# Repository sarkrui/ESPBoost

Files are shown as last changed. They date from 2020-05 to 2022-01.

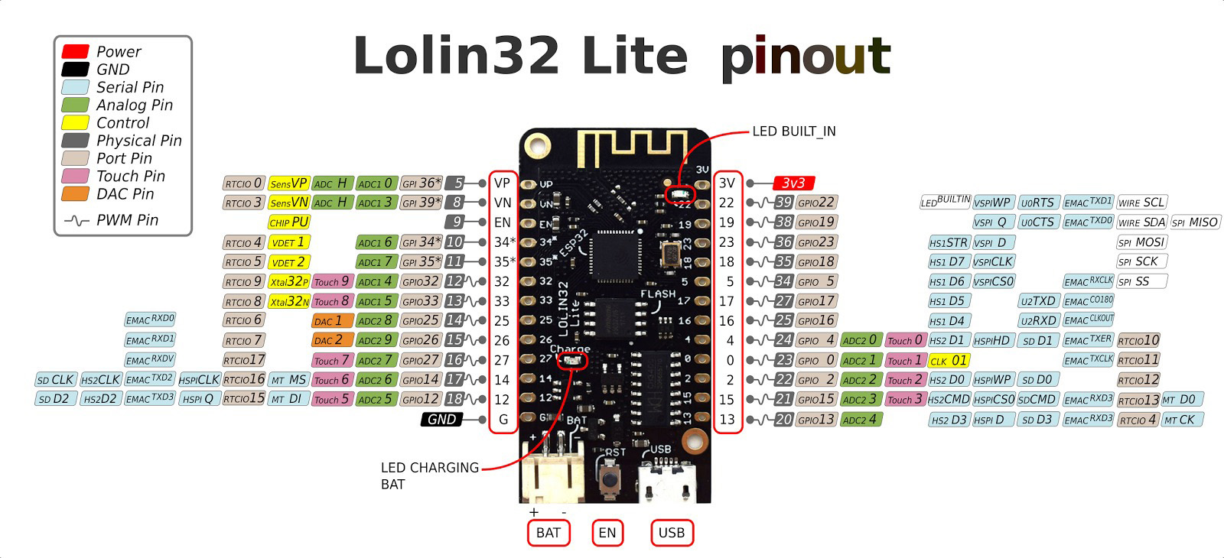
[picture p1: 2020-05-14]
Lolin32_files/Lolin32 Pinout.jpeg

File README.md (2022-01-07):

# ESPBoost
2SDCT8eYnrJI9NF

### Introduction
The ESPBoost is an ESP32 shield combines a **MPU6050** (3-axis gyro/accelerometer, via **SDA/SCL** GPIO), 2 H-Bridge motor drivers (**L9110s**, via GPIO **5**, **16**,**17**,**18** ), and a DC-DC (4.5V ~17v to 5V) power regulator (for powering up the ESP board via USB, allowing to charge Li-Po and the ESP32 MCU). Attaching this shield onto a Lolin32, actuations that demand high current (max. 800mA for each bridge), for example, driving two DC motors, and detections of angles, acceleration can be easily made possible. 

7GoLlhcizVjvBqO

### Components

* **Dual L9110s** (800 mA) DACs
* **MPU6050** Accelerometer and Gyroscope
* **TPS563201** Voltage regulator (4.5v to 17v input, 3A output)
* **FSR** (force sensitive resistor) connector  (A2 section)

### To-do

- [ ]  Include support for ESP32 minikit 
- [ ]  Incoporate [daisy chain support](https://i.imgur.com/pLPUlMk.jpg) for ESP boards (e.g. [TTGO T-Base](https://www.aliexpress.com/item/32888680096.html)) that come with an i2c connector (consisting of`SDA/SCL/3.3/GND` )
- [ ]  Add **ESPBoost-Input**, configured with 3-axis gyro/accelerometer (MPU6050), 12-pin capacitive sensor (MPR121q), FSR pull-down resistors
- [ ]  Add **ESPBoost-Actuation**, consisting of 2 sets of `TB6612FNG`
- [ ]  Add **ESPBoost-Power**, supporting battery charging, regulating voltage from 3.7V to 5V, 9V, 12V

### Pinout 

9usdo4JG2DMlhZ7

### Sample 
If you're interested in the field of Internet of Tangible Things, this shield may help. For sample inquiry, please drop me an email hi@pxing.design

### BibTex

```
@inproceedings{DBLP:conf/ewsn/XingC21,
  author    = {Sark Xing and
               Yaliang Chuang},
  title     = {ESPBoost: {A} Rapid Prototyping Toolkit for Helping Designers Create
               the Internet of Tangible Things},
  booktitle = {CHIIoT@EWSN/EICS},
  series    = {{CEUR} Workshop Proceedings},
  volume    = {2996},
  publisher = {CEUR-WS.org},
  year      = {2021}
}
```

### License

MIT License

Copyright (c) 2020 Sark Xing

Permission is hereby granted, free of charge, to any person obtaining a copy
of this software and associated documentation files (the "Software"), to deal
in the Software without restriction, including without limitation the rights
to use, copy, modify, merge, publish, distribute, sublicense, and/or sell
copies of the Software, and to permit persons to whom the Software is
furnished to do so, subject to the following conditions:

The above copyright notice and this permission notice shall be included in all
copies or substantial portions of the Software.

THE SOFTWARE IS PROVIDED "AS IS", WITHOUT WARRANTY OF ANY KIND, EXPRESS OR
IMPLIED, INCLUDING BUT NOT LIMITED TO THE WARRANTIES OF MERCHANTABILITY,
FITNESS FOR A PARTICULAR PURPOSE AND NONINFRINGEMENT. IN NO EVENT SHALL THE
AUTHORS OR COPYRIGHT HOLDERS BE LIABLE FOR ANY CLAIM, DAMAGES OR OTHER
LIABILITY, WHETHER IN AN ACTION OF CONTRACT, TORT OR OTHERWISE, ARISING FROM,
OUT OF OR IN CONNECTION WITH THE SOFTWARE OR THE USE OR OTHER DEALINGS IN THE
SOFTWARE.

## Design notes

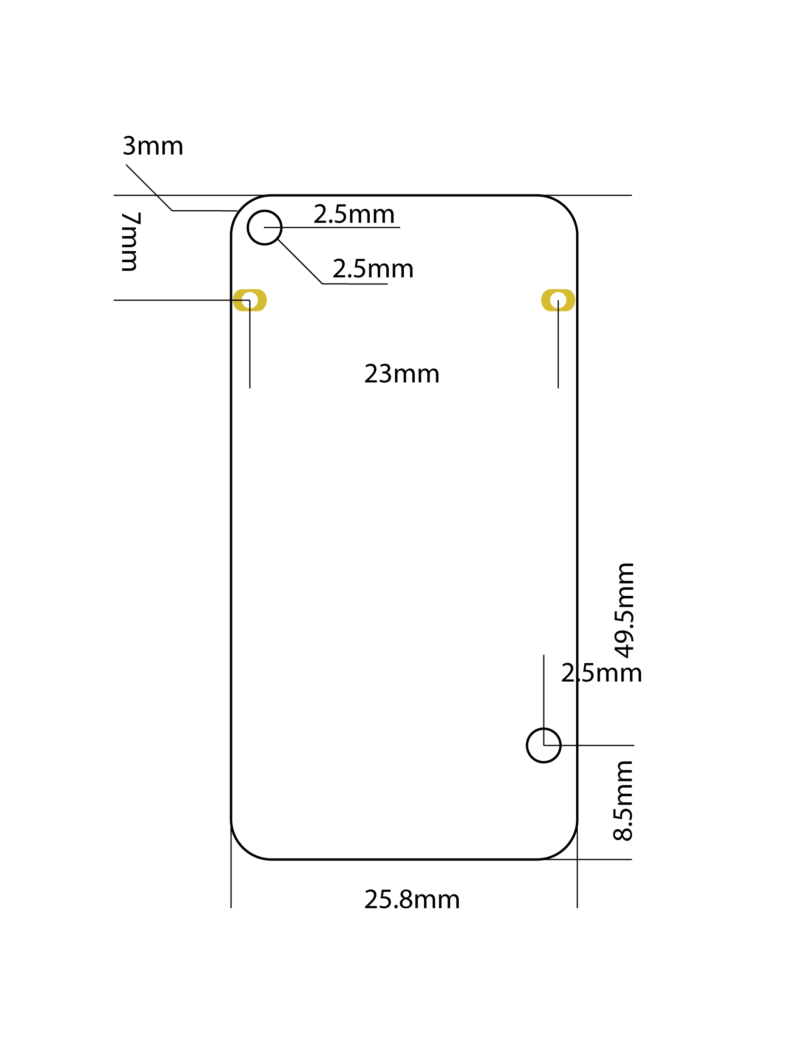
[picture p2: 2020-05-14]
Lolin32_files/Lolin32_dimensions.png

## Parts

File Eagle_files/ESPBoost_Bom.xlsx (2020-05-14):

 | Project | ESPBoost | Board Serial: | ESPBoost Rev1.0
# | Name | Value | Package | Mark | Amount
1 | SMD Ceramics Capacitor | 100n/25v | 0805 | C3, C4, C5, C9, C10, C13, C14, C15, C16, C19 | 10
2 | SMD Ceramics Capacitor | 10n/25v | 0806 | C17 | 1
3 | SMD Ceramics Capacitor | 10u/10v | 0807 | C2, C20 | 2
4 | SMD Ceramics Capacitor | 10u/25v | 1206 | C7, C8 | 2
5 | SMD Ceramics Capacitor | 2200pF | 0805 | C18 | 1
6 | Electrolytic capacitor | 220u/25v | ø8, d3.5mm | C1 | 1
7 | SMD Ceramics Capacitor | 22u/16v | 1206 | C11, C12 | 2
8 | SMD Inductance | 3.3uH/3A | SLF7032 | L1 | 1
9 | SMD Resistor | 4.7k | 0805 | R8, R9, R10 | 3
10 | SMD Resistor | 10k | 0805 | R1, R4, R5, R6, R7, R11, R12 | 7
11 | SMD Resistor | 1k | 0805 | R3 | 1
12 | SMD Resistor | 56.2k | 0805 | R2 | 1
13 | SMD LED | Red | 0805 | LED_+5V | 1
14 | Power Jack | DC-POWER-JACK | In-line | A1 | 1
15 | Motor Driver | L9110SO | SO08 | U4, U5 | 2
16 | Linear Regulator | LD117AS33TR | SOT223 | U2 | 1
17 | Accelerometer and Gyroscope | MPU6050 | QFN24 | U6 | 1
18 | DCDC | TPS563201DDC | SOT23-6L | U1 | 1
19 | ESP Pin | female | d2.54, 13 pins | U3 | 2
20 | Single-row pin header | male | d2.54, 4 pins | A4 | 1
21 | Double-row pin header | male | d2.54, 5 pins | A2 | 1
22 | JST2.0 | male | d2.54, 2 pins | MOTOR1, MOTOR2 | 2

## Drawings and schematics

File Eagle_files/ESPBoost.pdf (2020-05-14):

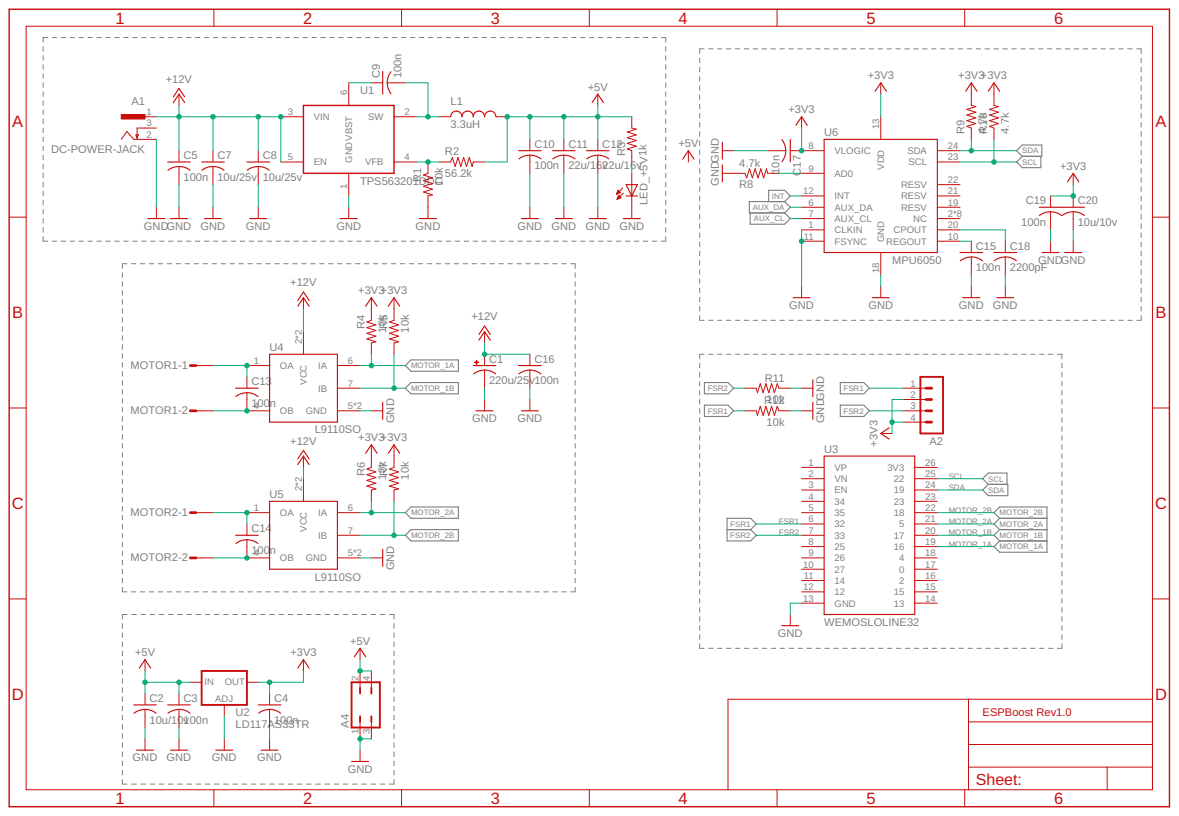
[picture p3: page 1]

ESPBoost Rev1.0

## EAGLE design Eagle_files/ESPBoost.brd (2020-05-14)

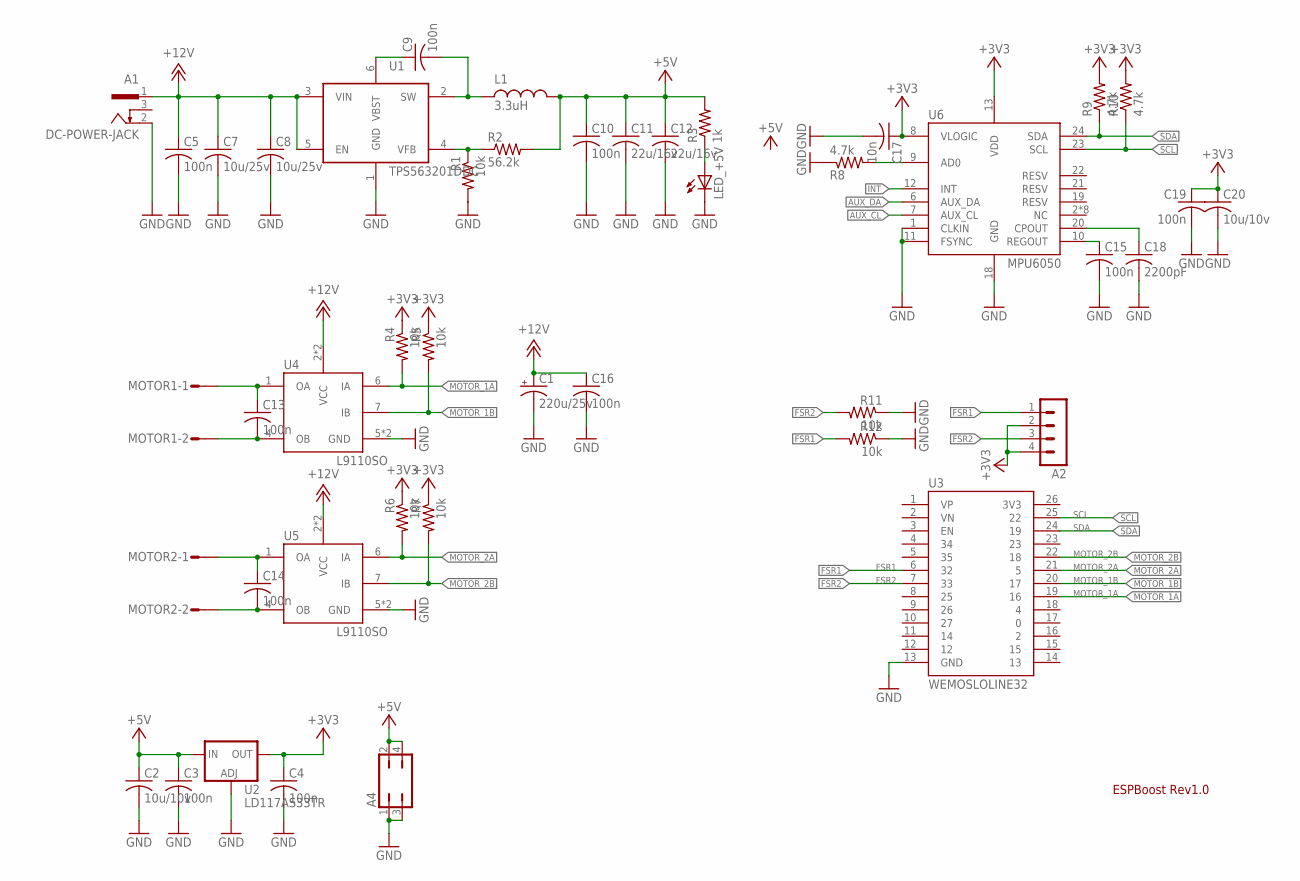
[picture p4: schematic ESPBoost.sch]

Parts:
A1: DC-POWER-JACK; DC-POWER
A2: MA04-1
A4: JP2Q
C1: 220u/25v; E3,5-8
C2, C20: 10u/10v; C0805
C3, C4, C5, C9, C10, C13, C14, C15, C16, C19: 100n; C0805
C7, C8: 10u/25v; C1206
C11, C12: 22u/16v; C1206
C17: 10n; C0805
C18: 2200pF; C0805
L1: 3.3uH; SLF7032TYPE
LED_+5V: LEDCHIPLED_0805; CHIPLED_0805
MOTOR1, MOTOR2: S02P
R1, R4, R5, R6, R7, R11, R12: 10k; R0805
R2: 56.2k; R0805
R3: 1k; R0805
R8, R9, R10: 4.7k; R0805
U1: TPS563201DDC; SOT23-6L
U2: LD117AS33TR; SOT223
U3: WEMOSLOLINE32; WEMOSLOLIN32
U4, U5: L9110SO; SO08
U6: MPU6050; QFN24

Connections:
+3V3: A2.2, A2.4, C4.1, C17.1, C19.1, C20.1, R4.1, R5.1, R6.1, R7.1, R9.2, R10.2, U2.4 (OUT), U6.8 (VLOGIC), U6.13 (VDD)
+5V: A4.2, A4.4, C2.1, C3.1, C10.1, C11.1, C12.1, L1.2, R2.2, R3.2, U2.3 (IN)
+12V: A1.1, C1.+, C5.1, C7.1, C8.1, C16.1, U1.3 (VIN), U1.5 (EN), U4.2 (VCC), U4.3 (VCC), U5.2 (VCC), U5.3 (VCC)
AUX_CL: U6.7 (AUX_CL)
AUX_DA: U6.6 (AUX_DA)
FSR1: A2.1, R12.2, U3.6 (32)
FSR2: A2.3, R11.2, U3.7 (33)
GND: A1.2, A4.1, A4.3, C1.-, C2.2, C3.2, C4.2, C5.2, C7.2, C8.2, C10.2, C11.2, C12.2, C15.2, C16.2, C17.2, C18.2, C19.2, C20.2, LED_+5V.C, R1.2, R8.1, R11.1, R12.1, U1.1 (GND), U2.1 (ADJ), U3.13 (GND), U4.5 (GND), U4.8 (GND), U5.5 (GND), U5.8 (GND), U6.1 (CLKIN), U6.11 (FSYNC), U6.18 (GND)
INT: U6.12 (INT)
MOTOR_1A: R4.2, U3.19 (16), U4.6 (IA)
MOTOR_1B: R5.2, U3.20 (17), U4.7 (IB)
MOTOR_1OA: C13.1, MOTOR1.1, U4.1 (OA)
MOTOR_1OB: C13.2, MOTOR1.2, U4.4 (OB)
MOTOR_2A: R6.2, U3.21 (5), U5.6 (IA)
MOTOR_2B: R7.2, U3.22 (18), U5.7 (IB)
MOTOR_2OA: C14.1, MOTOR2.1, U5.1 (OA)
MOTOR_2OB: C14.2, MOTOR2.2, U5.4 (OB)
unnamed: LED_+5V.A, R3.1
unnamed: C9.2, L1.1, U1.2 (SW)
unnamed: R1.1, R2.1, U1.4 (VFB)
unnamed: C9.1, U1.6 (VBST)
unnamed: R8.2, U6.9 (AD0)
unnamed: C15.1, U6.10 (REGOUT)
unnamed: C18.1, U6.20 (CPOUT)
SCL: R10.1, U3.25 (22), U6.23 (SCL)
SDA: R9.1, U3.24 (19), U6.24 (SDA)

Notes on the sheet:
ESPBoost Rev1.0

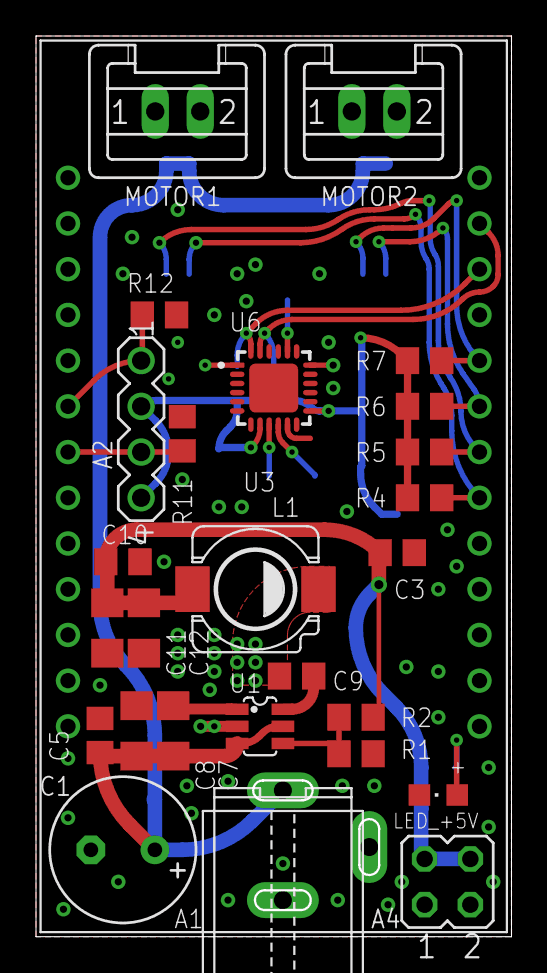
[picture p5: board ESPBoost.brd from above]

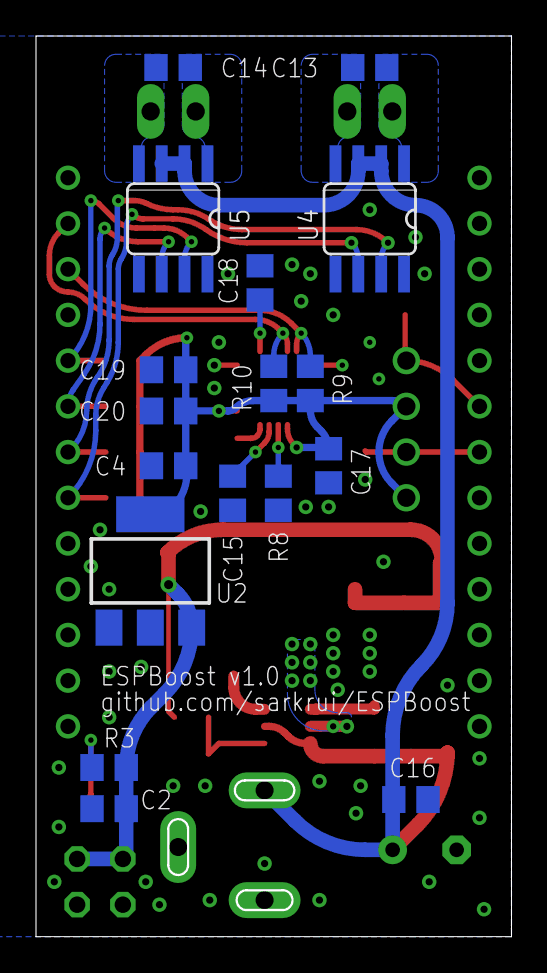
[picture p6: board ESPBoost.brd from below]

Board: 2 copper layers, 26.4 x 50.0 mm, 44 parts (17 on the bottom side), 23 nets.

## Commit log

2020-05-14 ESPBoost v1.0 inital release (PCB, Schematics, BOM)
    [ESPBoost.brd, ESPBoost.sch, ESPBoost_Bom.xlsx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]
2020-05-14 add board annotation
